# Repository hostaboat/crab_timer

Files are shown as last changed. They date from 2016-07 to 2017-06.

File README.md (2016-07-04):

A project using a Teensy 3.2 and various Adafruit breakout boards that is a gift to my crabber dad.

It allows him to keep a running count of the number of crabs caught during the season, set a default time and start a countdown timer for cooking them while playing music as he hangs around waiting.

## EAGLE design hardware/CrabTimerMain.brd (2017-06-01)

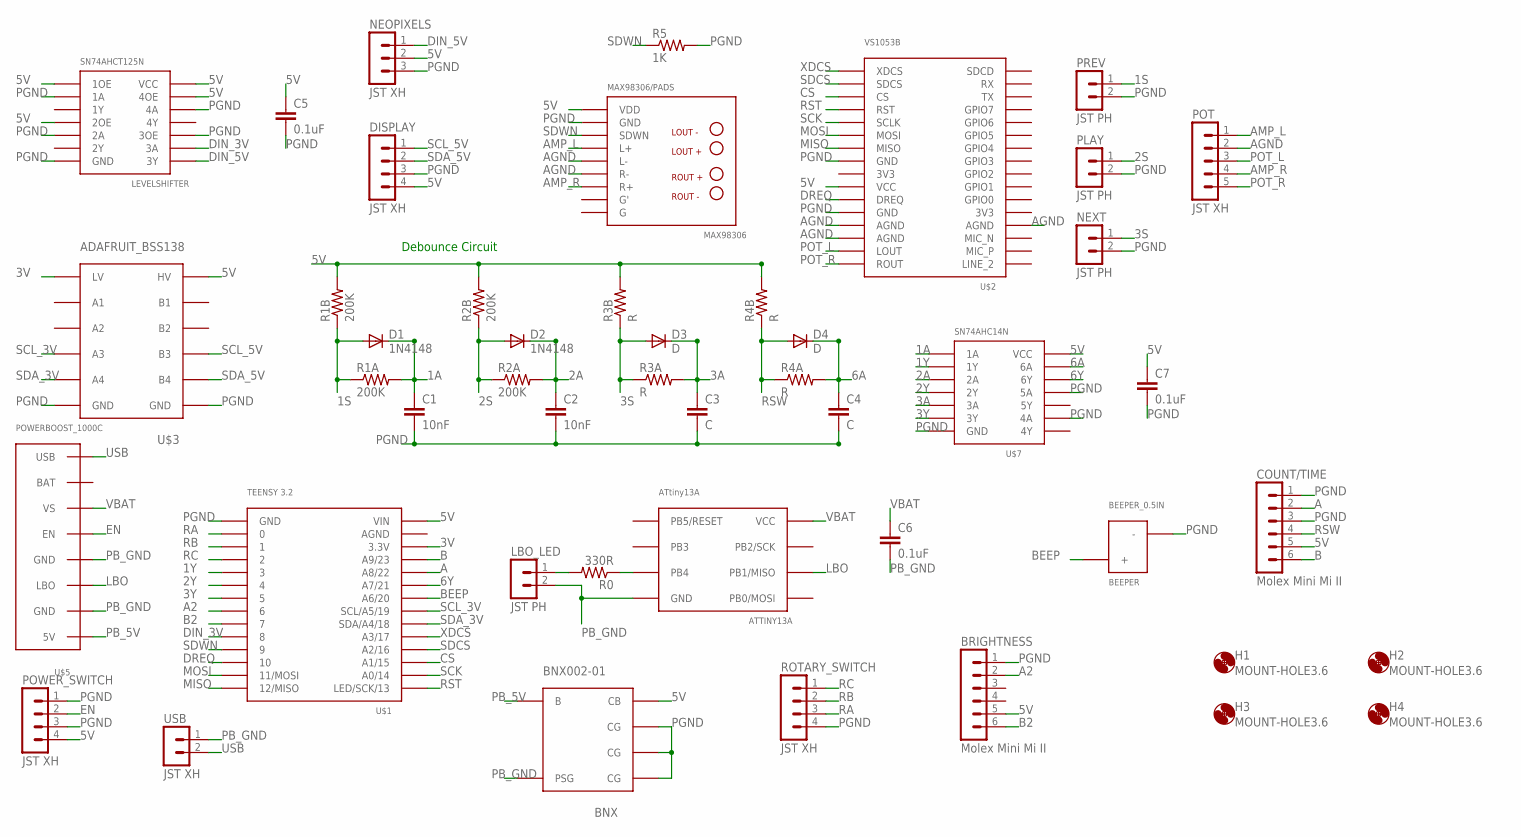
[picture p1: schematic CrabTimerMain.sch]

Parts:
ATTINY13A: ATtiny13A; ATTINY13A
BEEPER: BEEPER_0.5IN
BNX002-01: BNX; BNX002-01
BRIGHTNESS: Molex Mini Mi II; 55447-0670
C1, C2: 10nF; CAPACITOR_0.1IN
C3, C4: C; CAPACITOR_0.1IN
C5, C6, C7: 0.1uF; CAPACITOR_0.1IN
COUNT/TIME: Molex Mini Mi II; 55454-0670
D1, D2: 1N4148
D3, D4: D; 1N4148
DISPLAY: JST XH; B4B-XH-A
H1, H2, H3, H4: MOUNT-HOLE3.6; 3,6
LBO_LED: JST PH; B2B-PH-K-S
LEVELSHIFTER: SN74AHCT125N
MAX98306: MAX98306/PADS; MAX98306
NEOPIXELS: JST XH; B3B-XH-A
NEXT: JST PH; B2B-PH-K-S
PLAY: JST PH; B2B-PH-K-S
POT: JST XH; B5B-XH-A
POWER_SWITCH: JST XH; B4B-XH-A
PREV: JST PH; B2B-PH-K-S
R0: 330R; RESISTOR_0.15IN
R1A, R1B, R2A, R2B: 200K; RESISTOR_0.15IN
R3A, R3B, R4A, R4B: R; RESISTOR_0.15IN
R5: 1K; RESISTOR_0.15IN
ROTARY_SWITCH: JST XH; B4B-XH-A
U$1: TEENSY 3.2; TEENSY-3.1
U$2: VS1053B
U$3: ADAFRUIT_BSS138
U$5: POWERBOOST_1000C
U$7: SN74AHC14N
USB: JST XH; B2B-XH-A

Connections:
1A: C1.P$1 (1), D1.C, R1A.2, U$7.1A
1S: D1.A, PREV.1, R1A.1, R1B.1
1Y: U$1.3, U$7.1Y
2A: C2.P$1 (1), D2.C, R2A.2, U$7.2A
2S: D2.A, PLAY.1, R2A.1, R2B.1
2Y: U$1.4, U$7.2Y
3A: C3.P$1 (1), D3.C, R3A.2, U$7.3A
3S: D3.A, NEXT.1, R3A.1, R3B.1
3V: U$1.3.3V, U$3.LV
3Y: U$1.5, U$7.3Y
5V: BNX002-01.CB, BRIGHTNESS.5, C5.P$1 (1), C7.P$1 (1), COUNT/TIME.5, DISPLAY.4, LEVELSHIFTER.1OE, LEVELSHIFTER.2OE, LEVELSHIFTER.4OE, LEVELSHIFTER.VCC@1 (VCC), MAX98306.VDD@1 (VDD), NEOPIXELS.2, POWER_SWITCH.4, R1B.2, R2B.2, R3B.2, R4B.2, U$1.VIN, U$2.VCC, U$3.HV, U$7.VCC@1 (VCC)
6A: C4.P$1 (1), D4.C, R4A.2, U$7.6A
6Y: U$1.A7/21, U$7.6Y
A: COUNT/TIME.2, U$1.A8/22
A2: BRIGHTNESS.2, U$1.6
AGND: MAX98306.L-, MAX98306.R-, POT.2, U$2.AGND@1 (AGND), U$2.AGND@2 (AGND), U$2.AGND@3 (AGND)
AMP_L: MAX98306.L+, POT.1
AMP_R: MAX98306.R+, POT.4
B: COUNT/TIME.6, U$1.A9/23
B2: BRIGHTNESS.6, U$1.7
BEEP: BEEPER.+, U$1.A6/20
CS: U$1.A1/15, U$2.CS
DIN_3V: LEVELSHIFTER.3A, U$1.8
DIN_5V: LEVELSHIFTER.3Y, NEOPIXELS.1
DREQ: U$1.10, U$2.DREQ
EN: POWER_SWITCH.2, U$5.P$EN (EN)
LBO: ATTINY13A.PB1/MISO, U$5.P$LBO (LBO)
MISO: U$1.12/MISO, U$2.MISO
MOSI: U$1.11/MOSI, U$2.MOSI
unnamed: LBO_LED.1, R0.2
unnamed: ATTINY13A.PB4, R0.1
PB_5V: BNX002-01.B, U$5.P$5V (5V)
PB_GND: ATTINY13A.GND, BNX002-01.PSG, C6.P$2 (2), LBO_LED.2, U$5.P$GND@1 (GND), U$5.P$GND@2 (GND), USB.1
PGND: BEEPER.-, BNX002-01.CG@1 (CG), BNX002-01.CG@2 (CG), BNX002-01.CG@3 (CG), BRIGHTNESS.1, C1.P$2 (2), C2.P$2 (2), C3.P$2 (2), C4.P$2 (2), C5.P$2 (2), C7.P$2 (2), COUNT/TIME.1, COUNT/TIME.3, DISPLAY.3, LEVELSHIFTER.1A, LEVELSHIFTER.2A, LEVELSHIFTER.3OE, LEVELSHIFTER.4A, LEVELSHIFTER.GND@1 (GND), MAX98306.GND@1 (GND), NEOPIXELS.3, NEXT.2, PLAY.2, POWER_SWITCH.1, POWER_SWITCH.3, PREV.2, R5.2, ROTARY_SWITCH.4, U$1.GND, U$2.GND@1 (GND), U$2.GND@2 (GND), U$3.GND@1 (GND), U$3.GND@2 (GND), U$7.4A, U$7.5A, U$7.GND@1 (GND)
POT_L: POT.3, U$2.LOUT
POT_R: POT.5, U$2.ROUT
RA: ROTARY_SWITCH.3, U$1.0
RB: ROTARY_SWITCH.2, U$1.1
RC: ROTARY_SWITCH.1, U$1.2
RST: U$1.LED/SCK/13, U$2.RST
RSW: COUNT/TIME.4, D4.A, R4A.1, R4B.1
SCK: U$1.A0/14, U$2.SCLK
SCL_3V: U$1.SCL/A5/19, U$3.A3
SCL_5V: DISPLAY.1, U$3.B3
SDA_3V: U$1.SDA/A4/18, U$3.A4
SDA_5V: DISPLAY.2, U$3.B4
SDCS: U$1.A2/16, U$2.SDCS
SDWN: MAX98306.SDWN, R5.1, U$1.9
USB: U$5.P$USB (USB), USB.2
VBAT: ATTINY13A.VCC, C6.P$1 (1), U$5.P$VS (VS)
XDCS: U$1.A3/17, U$2.XDCS

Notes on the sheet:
Debounce Circuit

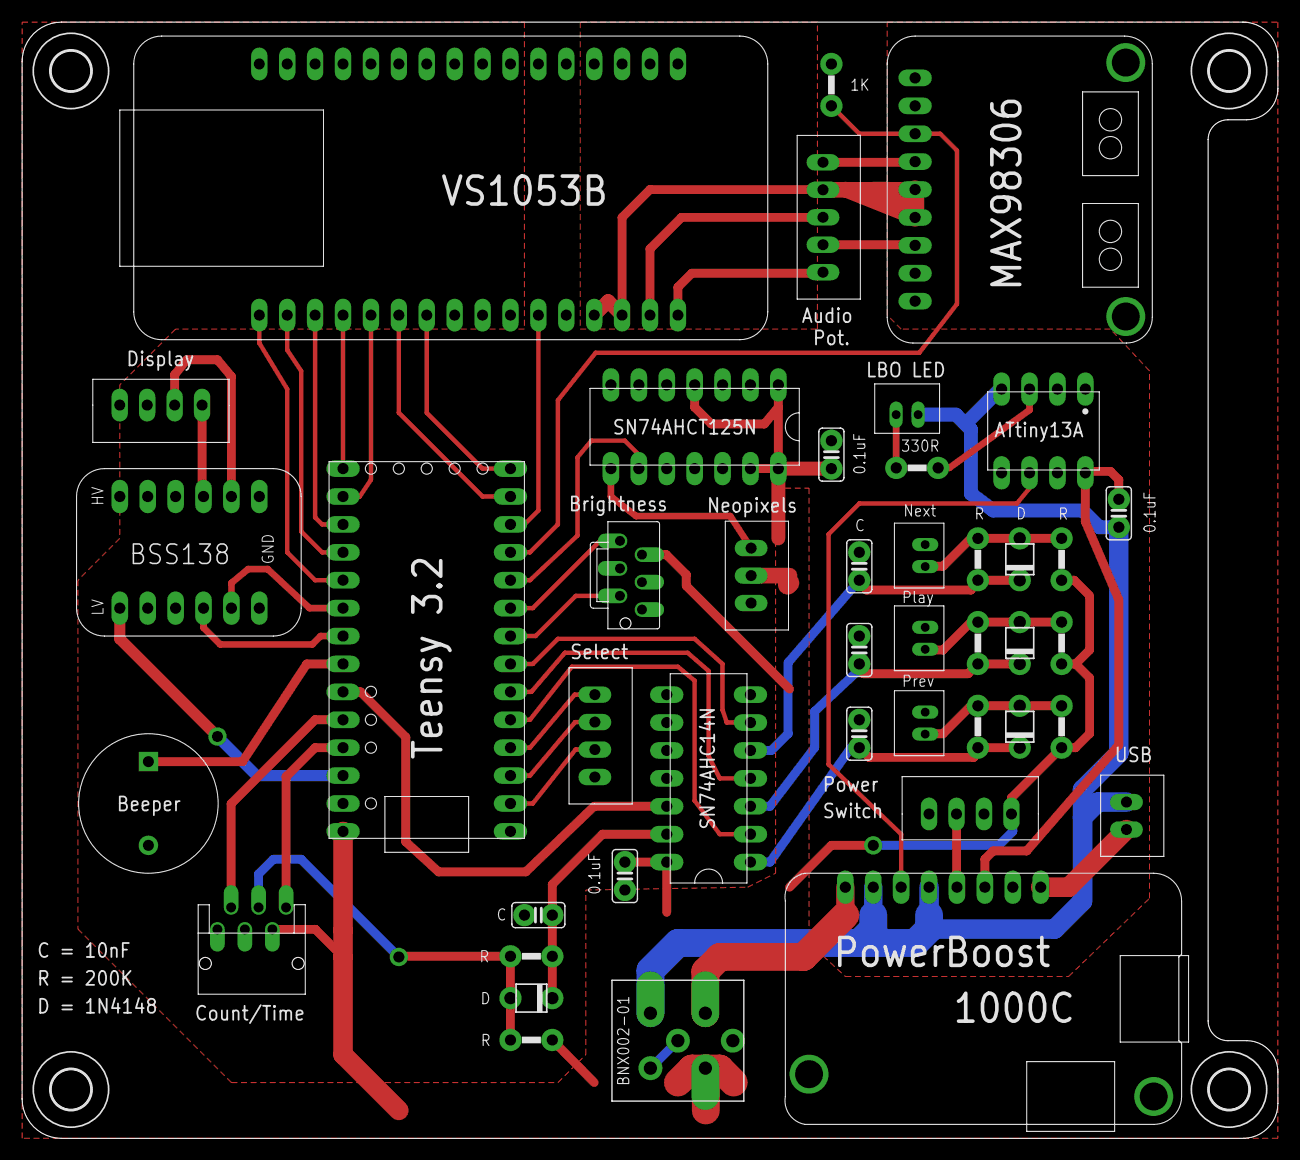
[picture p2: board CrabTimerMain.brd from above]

Board: 2 copper layers, 114.3 x 101.6 mm, 47 parts (0 on the bottom side), 51 nets.

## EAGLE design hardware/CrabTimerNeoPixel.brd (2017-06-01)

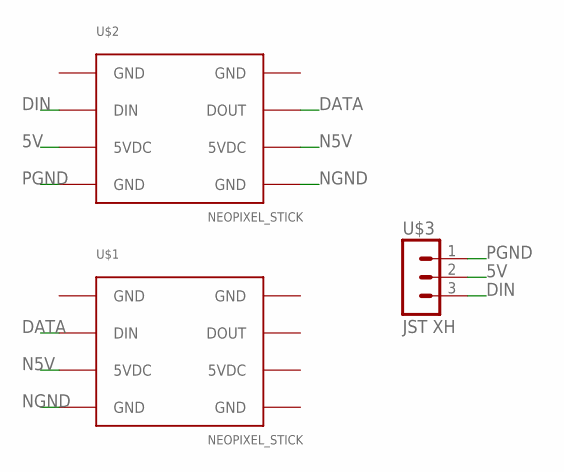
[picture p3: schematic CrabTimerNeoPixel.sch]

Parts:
U$1, U$2: NEOPIXEL_STICK; NEOPIXEL_STICK_SMD_SHORT/HOLES
U$3: JST XH; B3B-XH-A

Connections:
5V: U$2.5VDC@1 (5VDC), U$3.2
5VDC: U$1.5VDC@2 (5VDC)
DATA: U$1.DIN, U$2.DOUT
DIN: U$2.DIN, U$3.3
GND: U$1.GND@1 (GND), U$1.GND@3 (GND), U$1.GND@4 (GND), U$2.GND@1 (GND), U$2.GND@3 (GND)
N5V: U$1.5VDC@1 (5VDC), U$2.5VDC@2 (5VDC)
NGND: U$1.GND@2 (GND), U$2.GND@4 (GND)
PGND: U$2.GND@2 (GND), U$3.1

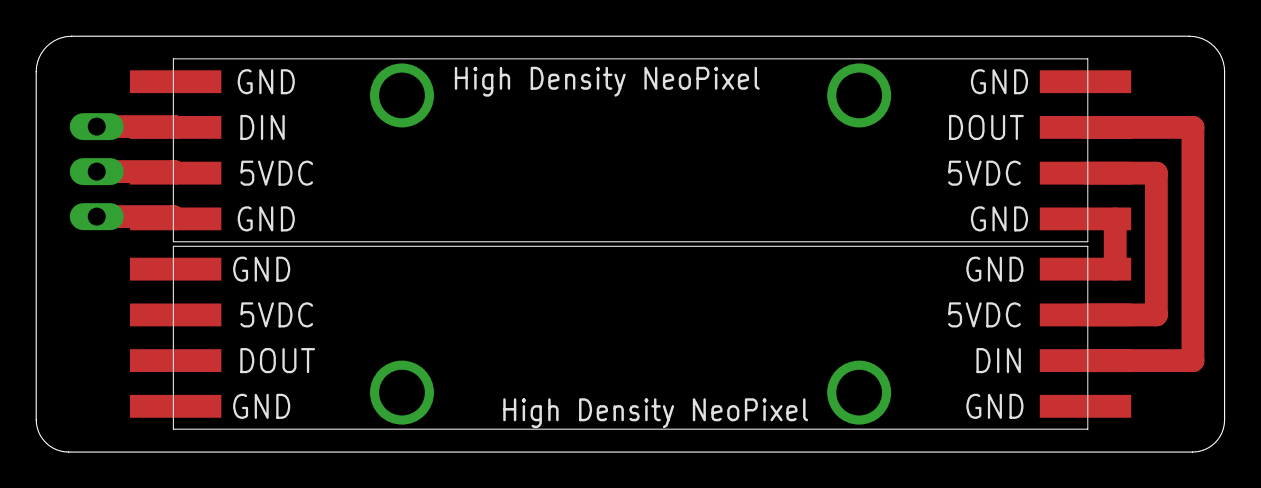
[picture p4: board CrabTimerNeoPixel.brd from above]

Board: 2 copper layers, 66.0 x 23.1 mm, 3 parts (1 on the bottom side), 7 nets.

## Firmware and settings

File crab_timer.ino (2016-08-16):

#include "pins.h"
#include "interface.h"

UserInterface s_interface;

void setup(void)
{
    //Serial.begin(9600);
    //while (!Serial);

    // Amplifier shutdown
    pinMode(PIN_AMP_SDWN, OUTPUT);
    GPIO::clear(PIN_AMP_SDWN);

    // VS1053 hardware reset pin
    pinMode(PIN_AUDIO_RST, OUTPUT);
    GPIO::clear(PIN_AUDIO_RST);

    // Beeper
    pinMode(PIN_BEEPER, OUTPUT);
    GPIO::clear(PIN_BEEPER);

    //////////////////////////////////////
    // SPI Chip select pins //////////////
    //////////////////////////////////////
    // SD
    pinMode(PIN_SD_CS, OUTPUT);
    GPIO::set(PIN_SD_CS);

    // VS1053 SCI
    pinMode(PIN_AUDIO_CS, OUTPUT);
    GPIO::set(PIN_AUDIO_CS);

    // VS1053 SDI
    pinMode(PIN_AUDIO_DCS, OUTPUT);
    GPIO::set(PIN_AUDIO_DCS);
    //////////////////////////////////////

    // VS1053 data request pin
    pinMode(PIN_AUDIO_DREQ, INPUT);
    pinMode(PIN_AUDIO_PLAY, INPUT);
    pinMode(PIN_AUDIO_NEXT, INPUT);
    pinMode(PIN_AUDIO_PREV, INPUT);

    // Rotary encoder for brightness
    pinMode(PIN_ROT_ENC_BR_A, INPUT_PULLUP);
    pinMode(PIN_ROT_ENC_BR_B, INPUT_PULLUP);

    // Rotary encoder and push switch
    pinMode(PIN_ROT_ENC_A, INPUT_PULLUP);
    pinMode(PIN_ROT_ENC_B, INPUT_PULLUP);
    pinMode(PIN_ROT_ENC_SW, INPUT);

    // Rotary switch
    pinMode(PIN_ROT_SWI_1, INPUT_PULLUP);
    pinMode(PIN_ROT_SWI_2, INPUT_PULLUP);
    pinMode(PIN_ROT_SWI_3, INPUT_PULLUP);

    s_interface.init();
}

void loop(void)
{
    s_interface.update();
}

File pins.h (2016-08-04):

#ifndef _PINS_H_
#define _PINS_H_

#include <cstdint>

#define PIN_ROT_SWI_1    0   // Rotary Switch 1
#define PIN_ROT_SWI_2    1   // Rotary Switch 2
#define PIN_ROT_SWI_3    2   // Rotary Switch 3
#define PIN_AUDIO_PREV   3   // Play previous audio file buttion
#define PIN_AUDIO_PLAY   4   // Play / Pause button
#define PIN_AUDIO_NEXT   5   // Play next audio file button
#define PIN_ROT_ENC_BR_A 6   // Rotary Encoder A - Brightness
#define PIN_ROT_ENC_BR_B 7   // Rotary Encoder B - Brightness
#define PIN_NEOPIXEL     8   // Neopixel strip
#define PIN_AMP_SDWN     9   // Amplifier Shutdown
#define PIN_AUDIO_DREQ  10   // VS1053 Data Request
#define PIN_MOSI        11   // SPI - MOSI / DOUT
#define PIN_MISO        12   // SPI - MISO / DIN
#define PIN_AUDIO_RST   13   // VS1053 Hardware Reset
#define PIN_SCK         14   // SPI - SCK
#define PIN_AUDIO_CS    15   // SPI - VS1053 Command Chip Select (SCI)
#define PIN_SD_CS       16   // SPI - SD Chip Select
#define PIN_AUDIO_DCS   17   // SPI - VS1053 Data Chip Select (SDI)
#define PIN_SDA         18   // I2C - SDA  (7-Segment Display)
#define PIN_SCL         19   // I2C - SCL  (7-Segment Display)
#define PIN_BEEPER      20   // Beeper
#define PIN_ROT_ENC_SW  21   // Rotary Encoder Switch
#define PIN_ROT_ENC_A   22   // Rotary Encoder A
#define PIN_ROT_ENC_B   23   // Rotary Encoder B

#define PIN_MAX   24

#define PIN0_PORT_REG    (*(volatile uint32_t *)0x4004A040)
#define PIN1_PORT_REG    (*(volatile uint32_t *)0x4004A044)
#define PIN2_PORT_REG    (*(volatile uint32_t *)0x4004C000)
#define PIN3_PORT_REG    (*(volatile uint32_t *)0x40049030)
#define PIN4_PORT_REG    (*(volatile uint32_t *)0x40049034)
#define PIN5_PORT_REG    (*(volatile uint32_t *)0x4004C01C)
#define PIN6_PORT_REG    (*(volatile uint32_t *)0x4004C010)
#define PIN7_PORT_REG    (*(volatile uint32_t *)0x4004C008)
#define PIN8_PORT_REG    (*(volatile uint32_t *)0x4004C00C)
#define PIN9_PORT_REG    (*(volatile uint32_t *)0x4004B00C)
#define PIN10_PORT_REG   (*(volatile uint32_t *)0x4004B010)
#define PIN11_PORT_REG   (*(volatile uint32_t *)0x4004B018)
#define PIN12_PORT_REG   (*(volatile uint32_t *)0x4004B01C)
#define PIN13_PORT_REG   (*(volatile uint32_t *)0x4004B014)
#define PIN14_PORT_REG   (*(volatile uint32_t *)0x4004C004)
#define PIN15_PORT_REG   (*(volatile uint32_t *)0x4004B000)
#define PIN16_PORT_REG   (*(volatile uint32_t *)0x4004A000)
#define PIN17_PORT_REG   (*(volatile uint32_t *)0x4004A004)
#define PIN18_PORT_REG   (*(volatile uint32_t *)0x4004A00C)
#define PIN19_PORT_REG   (*(volatile uint32_t *)0x4004A008)
#define PIN20_PORT_REG   (*(volatile uint32_t *)0x4004C014)
#define PIN21_PORT_REG   (*(volatile uint32_t *)0x4004C018)
#define PIN22_PORT_REG   (*(volatile uint32_t *)0x4004B004)
#define PIN23_PORT_REG   (*(volatile uint32_t *)0x4004B008)

#define PIN_PORT_REG(pin)   PIN ## pin ## _PORT_REG

#define PIN0_GPIO   (((PIN0_PORT_REG & 0x00000700) >> 8) == 1)
#define PIN1_GPIO   (((PIN1_PORT_REG & 0x00000700) >> 8) == 1)
#define PIN2_GPIO   (((PIN2_PORT_REG & 0x00000700) >> 8) == 1)
#define PIN3_GPIO   (((PIN3_PORT_REG & 0x00000700) >> 8) == 1)
#define PIN4_GPIO   (((PIN4_PORT_REG & 0x00000700) >> 8) == 1)
#define PIN5_GPIO   (((PIN5_PORT_REG & 0x00000700) >> 8) == 1)
#define PIN6_GPIO   (((PIN6_PORT_REG & 0x00000700) >> 8) == 1)
#define PIN7_GPIO   (((PIN7_PORT_REG & 0x00000700) >> 8) == 1)
#define PIN8_GPIO   (((PIN8_PORT_REG & 0x00000700) >> 8) == 1)
#define PIN9_GPIO   (((PIN9_PORT_REG & 0x00000700) >> 8) == 1)
#define PIN10_GPIO  (((PIN10_PORT_REG & 0x00000700) >> 8) == 1)
#define PIN11_GPIO  (((PIN11_PORT_REG & 0x00000700) >> 8) == 1)
#define PIN12_GPIO  (((PIN12_PORT_REG & 0x00000700) >> 8) == 1)
#define PIN13_GPIO  (((PIN13_PORT_REG & 0x00000700) >> 8) == 1)
#define PIN14_GPIO  (((PIN14_PORT_REG & 0x00000700) >> 8) == 1)
#define PIN15_GPIO  (((PIN15_PORT_REG & 0x00000700) >> 8) == 1)
#define PIN16_GPIO  (((PIN16_PORT_REG & 0x00000700) >> 8) == 1)
#define PIN17_GPIO  (((PIN17_PORT_REG & 0x00000700) >> 8) == 1)
#define PIN18_GPIO  (((PIN18_PORT_REG & 0x00000700) >> 8) == 1)
#define PIN19_GPIO  (((PIN19_PORT_REG & 0x00000700) >> 8) == 1)
#define PIN20_GPIO  (((PIN20_PORT_REG & 0x00000700) >> 8) == 1)
#define PIN21_GPIO  (((PIN21_PORT_REG & 0x00000700) >> 8) == 1)
#define PIN22_GPIO  (((PIN22_PORT_REG & 0x00000700) >> 8) == 1)
#define PIN23_GPIO  (((PIN23_PORT_REG & 0x00000700) >> 8) == 1)

#define PIN_GPIO(pin)     PIN ## pin ## _GPIO

#define GPIO_PIN0_PDOR  (*(volatile uint32_t *)0x43fe0840)
#define GPIO_PIN0_PSOR  (*(volatile uint32_t *)0x43fe08c0)
#define GPIO_PIN0_PCOR  (*(volatile uint32_t *)0x43fe0940)
#define GPIO_PIN0_PTOR  (*(volatile uint32_t *)0x43fe09c0)
#define GPIO_PIN0_PDIR  (*(volatile uint32_t *)0x43fe0a40)
#define GPIO_PIN0_PDDR  (*(volatile uint32_t *)0x43fe0ac0)
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

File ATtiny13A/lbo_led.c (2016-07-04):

#include <avr/io.h>
#include <avr/sleep.h>
#include <avr/interrupt.h>
#include <util/delay.h>

ISR(INT0_vect)
{
    PORTB |= (1 << PORTB4);
    _delay_ms(1);
    PORTB &= ~(1 << PORTB4);
}

int main(int argc, char** argv)
{
    MCUCR = 0;
    GIMSK = 0;
    DDRB = 0;
    PORTB = 0;

    // Set PB4 as output for LED
    DDRB |= (1 << DDB4);

    // Set PB1/INT0 as input with pullup enabled
    //PORTB |= (1 << PORTB1);

    // Set interrupt INT0 as active low
    // This will trigger when LBO from PowerBoost goes low
    GIMSK |= (1 << INT0);

    // Setup MCU for Power-down mode
    set_sleep_mode(SLEEP_MODE_PWR_DOWN);
    sleep_enable();
    sleep_bod_disable();

    // Enable interrupts
    sei();

    // Just sleep in power-down mode only waking for INT0 interrupt
    while (1)
        sleep_cpu();

    return 0;
}

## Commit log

2016-02-19 Update player button debounce timeout from 100 to 200 ms. Really just testing GIT.
2016-02-28 * Updated how putting the display and leds to sleep. * Added low battery alerting * Added some more GPIO defines
2016-03-01 * Integrated LLWU code into UserInterface so as to turn most of everything off. (1) 15 seconds of rotary encoder inactivity turns leds and led display off (2) 15 minutes (1 minute for testing for now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
2016-03-03 * Add nvr.h and nvr.cpp - Non-Volatile Ram or EEPROM. Forces 32-bit reads and writes though can read 8, 16 and 32-bit. * Add intr.h and intr.cpp for managing interrupt handlers for pins. Needed abili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
2016-03-03 iTunes seems to add a hidden file with each audio file that has an M4A extension. Check for ATTR_HIDDEN to filter out these files.
2016-03-04 * Update low battery handling. - Remove UI_STATE__LOW_BAT and use a bool variable - Since the music player can cause intermittent voltage drops, first try to reduce the volume incrementally on each r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
    [interface.cpp, player.cpp]
2016-03-04 Consolidate displaySleep() and CPUSleep() into sleep(). Resets _sleep time if player occupied and display asleep so CPU doesn't go directly to sleep when say player is paused.
    [interface.cpp]
2016-03-06 * Added a loadPlugin() function to the player for applying the above patch. * Set PIN_AMP_SDWN on startup and clear when player is disabled instead of clearing when player is paused or stopped and se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
    [interface.cpp, player.cpp]
2016-03-06 Have to explicitly set _timer_pause to 0 before going into TIMER_STATE__DONE so sleep isn't entered and on switch press is processed in time().
2016-03-06 Add simplified I2C interface that only supports writes from one master to one slave with MCU as master. Default clock of 400kHz.
2016-03-07 * Add I2C STOP condition to display standby and START to wake. Seems to save a milliamp or two. * Allow player disable mode to be re-enabled by resume. Only shut down amp when disabled. I may be goin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
2016-03-07 * Start player in stopped state * Stop player after some time even if timer is running.
2016-03-16 Update pin assignments for circuit board prototype.
2016-03-18 * Try to fix speaker pop. Seems that adding ~350ms delay between turning on VS1053 and the amplifier suppresses it. * Make disabling player permanent.
    [interface.cpp, player.cpp]
2016-04-01 Decided to use a rotary encoder with detents so as to eliminate the possible increment or decrement when it's on the edge and the switch is pressed. Also gives a tactile feeling of change. Both pins 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
2016-04-28 * Added rotary encoder to control brightness of 7-segment display and Neopixels. The initial values are set at mid levels for each - 128 for Neopixels and 7 for 7-segment display. - Added interrupt c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
2016-05-01 * Add code to timer interrupts so that it doesn't override display if the brightness is set to off. * Add code to guard against brightness interrupt updating display while an I2C communication is alr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
    [display.cpp, i2c.cpp, interface.cpp]
2016-05-03 * Get rid of ledsOn() and ledsOff() methods since they were really held over from when a transistor was being used to control the Neopixels. It was creating a situation where if the player was off an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
    [interface.cpp]
2016-07-04 Moved main code into teensy32/ directory and added the ATtiny13A code that controls the LBO LED into an directory called attiny13a/.
2016-07-04 Revert "Moved main code into teensy32/ directory and added the ATtiny13A code that"
    This reverts commit 6419a6540b8c467a0b4d8d68ba78888cddd0e014.
    Conflicts:
    attiny13a/Makefile
    attiny13a/lbo.c
    [crab_timer.ino, display.cpp, i2c.cpp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]
2016-07-04 Add ATtiny13A code for the LBO LED.
2016-07-04 Add notes concerning setting up for the Arduino environment.
2016-07-22 Changed PCB layout - swapped brightness rotary encoder pins with NeoPixel pin.
    [pins.h]
2016-08-04 Rename rotary switch from A/B/C to 1/2/3 and swap positions.
    [crab_timer.ino, interface.cpp, pins.h]
2017-06-01 Added Eagle schematic and board files
    [CrabTimerMain.brd, CrabTimerMain.sch, CrabTimerNeoPixel.brd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]
2017-06-01 Remove USB boards that were made using an Othermill and used for initial testing.
    [CrabTimerUSB_PWR.brd, CrabTimerUSB_PWR.sch]
